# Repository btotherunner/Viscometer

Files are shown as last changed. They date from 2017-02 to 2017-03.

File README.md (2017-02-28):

# Viscometer
Viscometer zur viskositätsmessung von Leim und automatischer Zugabe von Wasser

Mit diesem Viscometer kann die viskosität des Leims erfasst und verarbeitet werden, der Leim befindet sich in einem Heizbad und
und verliert dauerhaft Wasser.
Diesen Wasserverlust gleicht der Viscometer automatisch aus.

Anhand eines Stromssensors im Motorshield wird die viskosität bestimmt. Wird der Leim fester wird mehr Strom benötigt...

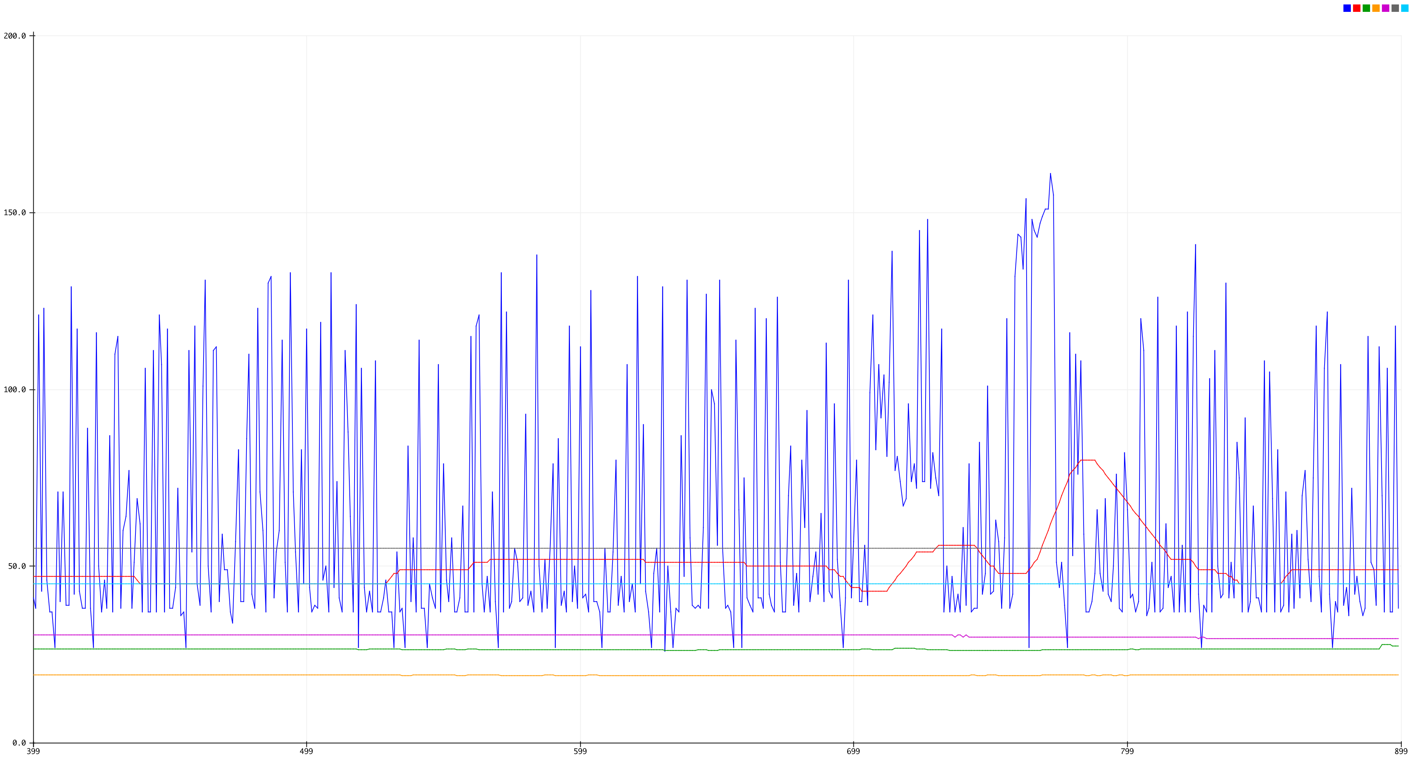
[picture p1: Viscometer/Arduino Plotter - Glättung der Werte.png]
Glättung der analog Werte


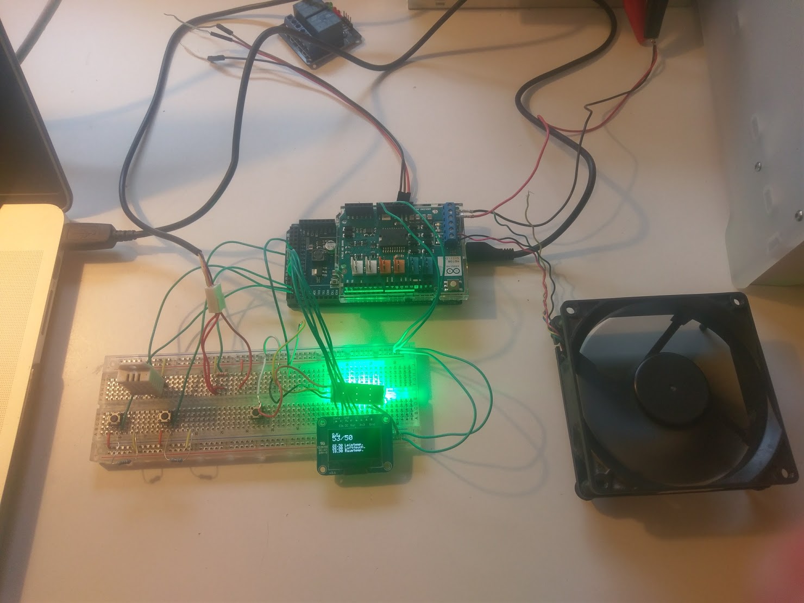
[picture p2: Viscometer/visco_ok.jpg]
Status


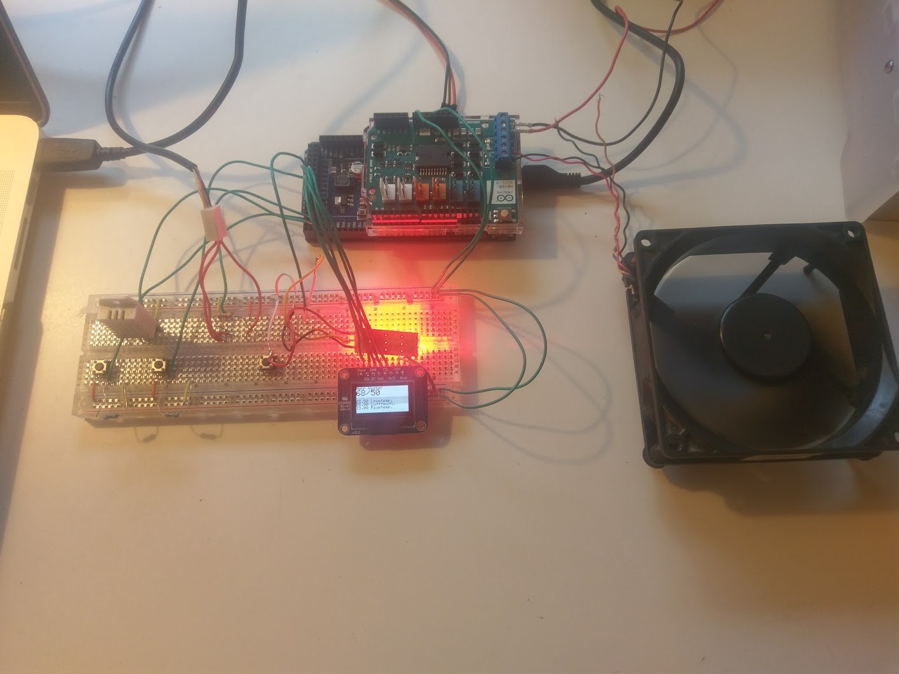
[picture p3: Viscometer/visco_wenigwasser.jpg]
zu Wenig Wasser


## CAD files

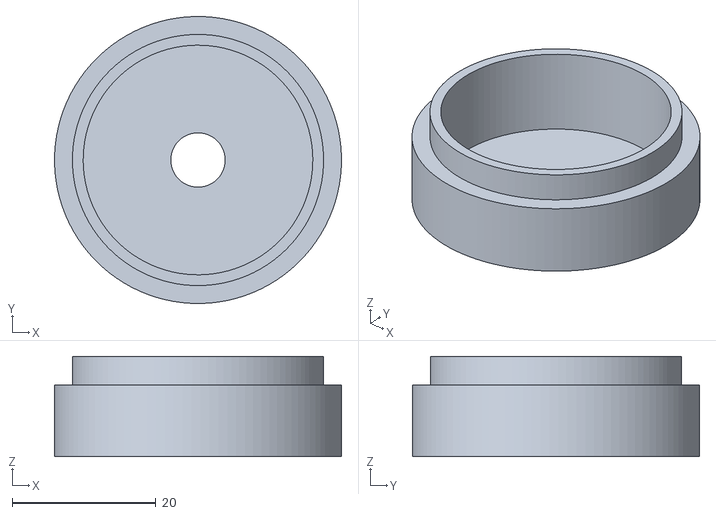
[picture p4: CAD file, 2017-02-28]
Viscometer/Sketchup_LED-Gehäuse_unten.stl
40.0 x 40.0 x 14.0

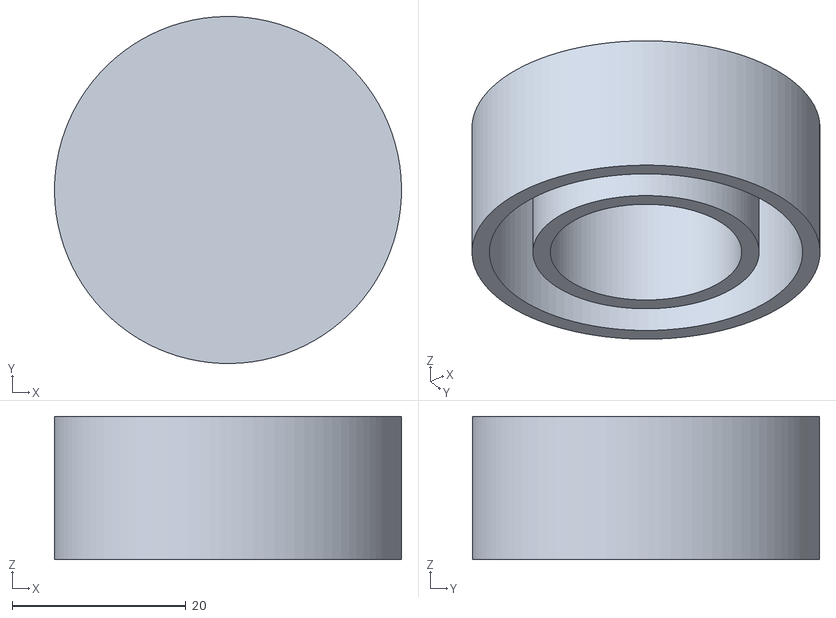
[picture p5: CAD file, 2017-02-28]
Viscometer/Sketchup_LED-Gehäuse_oben.stl
40.0 x 40.0 x 16.5

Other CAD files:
Viscometer/Sketchup_LED-Gehäuse.skp
Viscometer/Sketchup_LED-Gehäuse~.skp

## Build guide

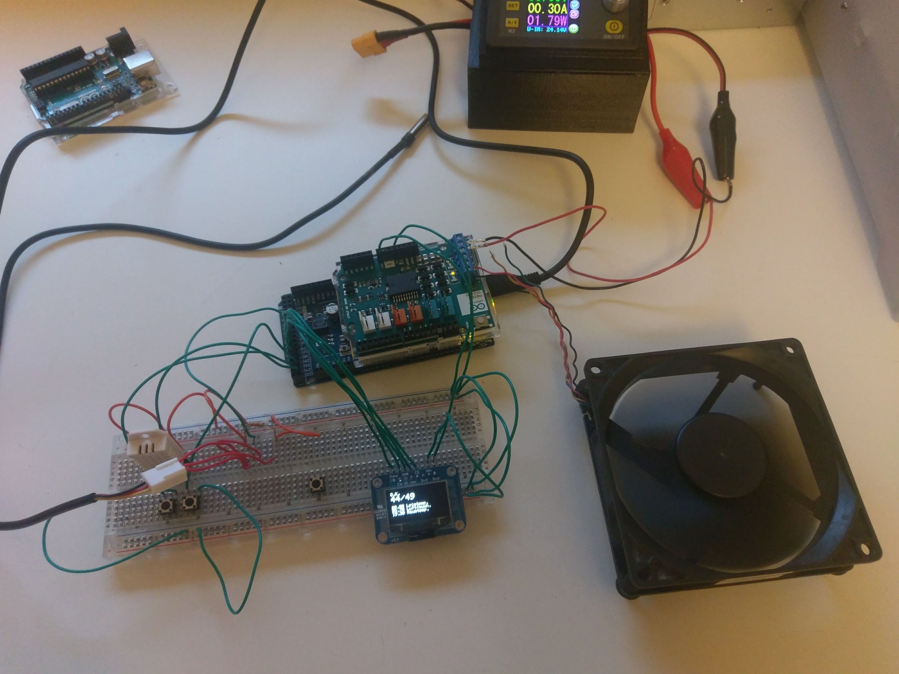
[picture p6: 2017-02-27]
Viscometer/Aufbau - Testphase.jpg

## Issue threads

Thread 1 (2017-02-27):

Arduino Due - gegen Mega tauschen

btotherunner, 2017-02-27:
Die Ansteuerung des Relais fehlt.
Da der Arduino Due nur 3.3V am Ausgang hat - das vorhandene Relais aber 5V verlangt - werde ich den Due gegen ein "Arduino Mega 2560, ATmega 2560, USB" ersetzen.

Closed 2017-03-03.

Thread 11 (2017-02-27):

Zeitlicher Wasserfluss definieren (Timeout)

btotherunner, 2017-02-27:
Damit nicht zuviel Wasser auf einem einläuft - sollte der Wasser zufaul Zeitlich definiert sein.
Und danach erstmal eine Zeit-X gewartet werden, da sich die Flüssigkeit träge verhält und alles ersteinmal gemischt werden muss.

btotherunner, 2017-03-01:
Timeout eingebaut

Closed 2017-03-01.

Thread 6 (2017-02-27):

Richtigen Motor auswählen

btotherunner, 2017-02-27:
Richtigen Motor ermitteln:

GM30 21 12V
Getriebemotor 30 mm, 21:1, 12 V DC

GM39,6 30 12V
Getriebemotor 39,6 mm, 30:1, 12 V DC

Closed 2020-12-29.

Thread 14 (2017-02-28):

Fehler Displayanzeige - wenn Temp unter Wert X ist beheben

btotherunner, 2017-02-28:
Wenn die Temp. unter Wert X ist.

Steht das Display - es sollte hier eine Meldung "Leim zu kalt" kommen und die Aktuelle Temp. /Soll Wert angezeigt werden.

btotherunner, 2017-02-28:
display.display(); hat gefehlt... und kleinere Anpassungen der Anzeige.

Closed 2017-02-28.

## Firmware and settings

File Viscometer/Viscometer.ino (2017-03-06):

int StartWertMessung;                                              //Definiert die Variabel StartWertMessung und setzt den Wert auf X
int TolleranzWert = 5;                                                  //Definiert die Variable TolleranzWert (ist der Wert - in der der Viscositätswert schwanken darf...)
int eepromBeckenTemp;
int BeckenMinTemp;
int mittelwert;

#include <EEPROM.h>

//Start Display
#include <SPI.h>                                                        //Lade Extension für OLED
#include <Wire.h>                                                       //Lade Extension für OLED
#include <Adafruit_GFX.h>                                               //Lade Extension für OLED
#include <Adafruit_SSD1306.h>                                           //Lade Extension für OLED
#define OLED_MOSI   39                                                  //Data port zum OLED Display
#define OLED_CLK   37                                                   //CLK port zum OLED Display
#define OLED_DC    35                                                   //DC Port zum OLED DISPLAY
#define OLED_CS    31                                                   //CS Port zum OLED Display
#define OLED_RESET 33                                                   //RST Port zum OLED Display
Adafruit_SSD1306 display(OLED_MOSI, OLED_CLK, OLED_DC, OLED_RESET, OLED_CS);            //Initialisiere das OLED Display
#define NUMFLAKES 10
#define XPOS 0
#define YPOS 1
#define DELTAY 2
//Ende Display

//LED Leiste
#include <Adafruit_NeoPixel.h>                                          //Lade Extension für LED-Leiste WS
#ifdef __AVR__
#include <avr/power.h>                                                  //Lade Extension für LED-Leiste WS
#endif
#define PIN 45                                                          //Definiert den digital PIN der LED Leiste  
#define NUMPIXELS 8                                                     //Definiert die Anzahl der LED´s am Port
Adafruit_NeoPixel pixels = Adafruit_NeoPixel(NUMPIXELS, PIN, NEO_GRB + NEO_KHZ800);       //Initialisiere die Lib. für die LED-Leiste
//Ende LED Leiste


//Taster
const int buttonPinPlus = 24;                                           //Definiert den digitalen PIN für den Plus Taster
const int buttonPinMinus = 25;                                          //Definiert den digitalen PIN für den Minus Taster
int buttonState = 0;                                                    //Definiiert die Variable buttonState und setzt sie auf 0;
int SollWert = StartWertMessung;                                        //Definiert die Variable SollWert und weißt Ihr einen definierten Startwert zu
//ENDE TASTER


//RELAY
const int relaisPin = 26;                                               //Definiert einen PWM Port für das schalten des Relais.
//ENDE RELAY


// Variablen zum Glätten
int FiltVal = StartWertMessung;                                       //Definiert Variable zum glätten der Werte
int FF;                                                               //Definiert den Glättungsfaktor 1=werte werden 1:1 übernommen 9=es werden nur 10% veränderung übernommen
int NewVal = StartWertMessung;                                        //Definiert Variable zum glätten der Werte
//Ende Variablen zum Glätten

//BEGIN MOTOR BOARD
//Channel B
int directionPin = 13;                                                //Definiert für Channel B am Motorshield den Port
int pwmPin = 11;                                                      //Definiert für Channel B am Motorshield den Port
int brakePin = 8;                                                     //Definiert für Channel B am Motorshield den Port
int currentPin = A15;                                                  //Definiert für Channel B am Motorshield den Port
//ENDE MOTOR

//START DS TEMP
#include <OneWire.h>                                                  //Lade Lib für den wasserdichten Beckentemperaturfühler
#include <DallasTemperature.h>                                        //Lade Lib für den wasserdichten Beckentemperaturfühler

#define ONE_WIRE_BUS 41                                               //Definiert den PIN den wasserdichten Beckentemperaturfühler
OneWire oneWire(ONE_WIRE_BUS);
DallasTemperature sensors(&oneWire);
//END DS TEMP

//START DHT SENSOR TEMP/HYM                                           //Lade Lib für den kombinierten Raumluft Temp/Feuchtigkeits Sensor
#include "DHT.h"                                                      //Lade Lib für den kombinierten Raumluft Temp/Feuchtigkeits Sensor            
#define DHTPIN 22                                                     //Definiert den PIN für den Raumluft Temp/Feuchtigkeits Sensor
#define DHTTYPE DHT22                                                 //Definiere TYP für den den Raumluft Temp/Feuchtigkeits Sensor
DHT dht(DHTPIN, DHTTYPE);
//END DHT SENSOR



void setup() {
  Serial.begin(9600);                                                 //Initialisiere Serielle-Schnittstell


  //LED LEISTE
#if defined (__AVR_ATtiny85__)
  if (F_CPU == 16000000) clock_prescale_set(clock_div_1);
#endif
  pixels.begin();                                                     //Initialisiere NeoPixel LED Leiste
  //ENDE LED LEISTE

  //RELAYS
  pinMode(relaisPin, OUTPUT);                                          // Den PWM PIN "relaisPin" als Ausgangssignal setzen.
  //RELAYS END

  //TASTER
  pinMode(buttonPinPlus, INPUT);                                      //Setzt den Taster Port als Input
  pinMode(buttonPinMinus, INPUT);                                     //Setzt den Taster Port als Input
  //ENDE TASTER

  // Start MOTOR
  pinMode(directionPin, OUTPUT);                                      //Initiates Motor Channel B pin
  pinMode(brakePin, OUTPUT);                                          //Initiates Brake Channel B pin
  //ENDE MOTOR

  //START DS TEMP
  sensors.begin();                                                        //Initialisiere Beckentemperatur
  //END DS TEMP

  //DHT BEGIN
  dht.begin();                                                            //Initialisiere Raumfeuchtigkeit & Raumtemperatur Sensor
  //DHT END

  //START DISPLAY
  // by default, we'll generate the high voltage from the 3.3v line internally! (neat!)
  display.begin(SSD1306_SWITCHCAPVCC);
  // init done
  // Clear the buffer.
  display.clearDisplay();                                                 //Leert das Display
  //Ende DISPLAY


  BeckenMinTemp = EEPROM.read(0);                                        //EEPROM AUSLESEN Beckentemp = 0
  SollWert = EEPROM.read(1);                                             //EEPROM AUSLESEN Viscositätssollwert = 1
  //SollWert = 325;
}


void loop() {

  


  //START DS TEMP
  sensors.requestTemperatures();                                          //fragt Beckentemperatur ab
  //ENDE DS TEMP

  //START DHT
  float h = dht.readHumidity();                                           //Luftfeuchte auslesen
  float t = dht.readTemperature();                                        //Temperatur auslesen
  //END DHT

  //temp abfrage des Beckens -- start des Motor

  //Temp unter XX°C kein start und led auf blau

  if (sensors.getTempCByIndex(0) < BeckenMinTemp) {                         //Wenn Temp zu Kalt:

    if (digitalRead(buttonPinPlus) == 0) {                                  //Taster für BeckenTempAnpassung
      BeckenMinTemp = BeckenMinTemp + 1;
      EEPROM.write(0, BeckenMinTemp);
    }
    if (digitalRead(buttonPinMinus) == 0) {                                 //Taster für BeckenTempAnpassung
      BeckenMinTemp = BeckenMinTemp - 1;
      EEPROM.write(0, BeckenMinTemp);                    //Daten in EEPROM Schreiben
    }

    //Relais
    digitalWrite(relaisPin, HIGH);                                           //Relais aus
    //Ende Relais

    //START DISPLAY AUSGABE
    //display.invertDisplay(false);                                          // Display wird invertiert angezeig d.h. weißer Hintergrund - schwarze Schrift
    display.setTextSize(2);
    display.setTextColor(WHITE);
    display.setCursor(0, 2);
    display.println(" ACHTUNG!");                                         //Fehler ausgabe auf dem Display
    display.setTextSize(1);
    display.println("  Leim zu kalt");                                    //Fehler ausgabe auf dem Display
    display.setTextSize(2);
    display.println(" ");                                                 //LeerZeile
    display.print(" "); display.print(sensors.getTempCByIndex(0)); display.print("/"); display.print(BeckenMinTemp); //Aktueller Wert (aktuellerwert/sollwert)
    display.display();                                                    //Display ausgabe
    display.clearDisplay();                                               //Leert das Display
    //ENDE DISPLAY AUSGABE

    //MOTOR AUS!
    digitalWrite(directionPin, HIGH);                                        //Schaltet den Motor aus
    digitalWrite(brakePin, HIGH);                                            //Schaltet den Motor aus
    analogWrite(pwmPin, 0);                                                  //Motor geschwindikeit aus
    //ENDE MOTOR AUS!

    // LED AUF BLAU!
    for (int i = 0; i < NUMPIXELS; i++) {
      pixels.setPixelColor(i, pixels.Color(0, 0, 255));                    // BLAUE LED
      pixels.show();                                                        // This sends the updated pixel color to the hardware.
    }
    //ENDE LED AUF BLAU

  }
  else {


    // Eigentlicher Start!!!

    //TASTER SOLL WERT
    if (digitalRead(buttonPinPlus) == 0) {
      SollWert = SollWert + 1;
      EEPROM.write(1, SollWert);
    }
    if (digitalRead(buttonPinMinus) == 0) {
      SollWert = SollWert - 1;
      EEPROM.write(1, SollWert);
    }
    //ENDE TASTER SOLLWERT

    //Relais
    digitalWrite(relaisPin, HIGH);                                           //Relais aus
    //Ende Relais

    //START MOTOR
    //backward @ half speed
    digitalWrite(directionPin, HIGH);                                           //Establishes forward direction of Channel A
    digitalWrite(brakePin, LOW);                                                //Disengage the Brake for Channel A
    analogWrite(pwmPin, 255);                                                   //Spins the motor on Channel A at full speed
    //ENDE  MOTOR

    //glaetten der werte
    NewVal = analogRead(currentPin);
    FF = 5;
    FiltVal = ((FiltVal * FF) + NewVal) / (FF + 1.0);
    
    //FiltVal = analogRead(currentPin);         //Ausgabe des original Werts

    display.setCursor(0, 0);                                                  //Setzt für das OLED DISPLAY den Beginn auf 0.0 und die Schriftfarbe auf Weiß.
    display.setTextColor(WHITE);

    //Tolleranz abfrage
    if (FiltVal > (SollWert + TolleranzWert)) {
      //display.invertDisplay(true);
      digitalWrite(relaisPin, LOW);                                          //Relais an
      display.setTextSize(1);
      display.setTextColor(WHITE);
      display.println("Mehr Wasser");                                      // Leere Zeile
      display.setTextSize(2);
      //display.setTextColor(BLACK, WHITE);                                   // 'inverted' text
      display.print(FiltVal); display.print("/"); display.println(SollWert);

      for (int i = 0; i < NUMPIXELS; i++) {
        pixels.setPixelColor(i, pixels.Color(255, 0, 0));                   // Orange ROT
        pixels.show();                                                        // This sends the updated pixel color to the hardware.
      }

    }
    else if (FiltVal < (SollWert - TolleranzWert)) {
     // display.invertDisplay(true);
      digitalWrite(relaisPin, HIGH);                                          //Relais aus
      display.setTextSize(1);
      display.setTextColor(WHITE);
      display.println("Weniger Wasser");                                      // Leere Zeile
      display.setTextSize(2);
      //display.setTextColor(BLACK, WHITE);                                   // 'inverted' text
      display.print(FiltVal); display.print("/"); display.println(SollWert);

      for (int i = 0; i < NUMPIXELS; i++) {
        pixels.setPixelColor(i, pixels.Color(255, 102, 0));                   // Orange LED
        pixels.show();                                                        // This sends the updated pixel color to the hardware.
      }
    }
    else {
      display.invertDisplay(false);
      digitalWrite(relaisPin, HIGH);                                           //Relais aus
      display.setTextColor(WHITE);
      display.setTextSize(1);
      display.setTextColor(WHITE);
      display.println("O.K.");                                                // Leere Zeile
      display.setTextSize(2);
      display.print(FiltVal); display.print("/"); display.println(SollWert);

      for (int i = 0; i < NUMPIXELS; i++) {
        pixels.setPixelColor(i, pixels.Color(0, 150, 0));                     // Grüne LED
        pixels.show();                                                        // This sends the updated pixel color to the hardware.
      }
    }
    //Ende Tolleranz

    display.setTextSize(1);
    display.setTextColor(WHITE);
    display.println(" ");                                                     // Leere Zeile
    display.print(sensors.getTempCByIndex(0));
    display.println(" Leimtemp.");                                            //Beckentemperatur
    display.print(h);
    display.println(" Luftfeuch.");                                           // Luftfeuchtigkeit
    display.print(t);
    display.println(" Raumtemp.");                                            // Ungebungslufttemperatur
    display.display();

    display.clearDisplay();
  }

  //ENDE DISPLAY AUSGABE

  Serial.print(FiltVal);                                               //Geglätteter Wert des Current Signals
  Serial.print("\t");
  Serial.print(h);                                                            //Raumfeuchtigkeit
  Serial.print("\t"); 
  Serial.print(t);                                                            //Raumtemperatur
  Serial.print("\t");
  Serial.print(sensors.getTempCByIndex(0));                                 //Beckentemperatur
  Serial.print("\t");
  Serial.print(SollWert + TolleranzWert);                                   //Ausgabe des Tolleranzwertes(max) im Plotter
  Serial.print("\t");
  Serial.println(SollWert - TolleranzWert);                                 //Ausgabe des Tolleranzwertes(min) im Plotter
}

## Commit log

2017-02-27 Basisfunktionen vorhanden (Fehlt: Relais & richtiger Motor)
    Arduino Due
    Motor Shield
    Temperaturfühler
    Feuchtigkeit und Temp Fühler
    OLED DISPLAY 128x32
    Druckschalter
    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
2017-02-27 Arduino Plotter - Glättung der Werte
2017-02-28 LED Leiste zur visuellen Darstellung hinzugefügt
    weitere Anpassungen vom Ablauf des Motors:
    Start erst ab Temp-X
    Display funktioniert aber noch nicht korrekt!
2017-02-28 Kommentieren des Codes
2017-02-28 Fehler im Merge behoben
    [Viscometer.ino]
2017-02-28 Display korrigiert - alles kommentiert
    [Viscometer.ino]
2017-02-28 LED Gehäuse (Sketchup)
    [Sketchup_LED-Gehäuse.skp, Sketchup_LED-Gehäuse_oben.stl, Sketchup_LED-Gehäuse_unten.stl]
2017-02-28 EEPROM für MEGA Board vorbereitet
2017-02-28 Blau neu definiert - Blinken deaktiviert
    [Sketchup_LED-Gehäuse.skp]
2017-02-28 SKP Upload
    [Sketchup_LED-Gehäuse.skp, Sketchup_LED-Gehäuse~.skp]
2017-03-01 Hinzufügen des max/min Tolleranzwertes für den Arduino Plotter
2017-03-01 EEPROM Speicher für Becken und StartTemp
2017-03-03 Update mit INA169
    Glättung wird nich mehr benötigt
    Serielle Aushabe angepasst
